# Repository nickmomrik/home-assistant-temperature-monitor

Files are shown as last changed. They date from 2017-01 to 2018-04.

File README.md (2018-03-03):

# Home Assistant - Temperature & Humidity Sensors
My goal with this project was to create a device I could leave in the garage, which would push temperature and humidity data to Home Assistant. I also wanted to be able to enable a "monitor" mode when I turn on the heat in the garage so the system would alert me when a certain temperature was reached. See the [working version on my blog](https://nickmomrik.com/2017/01/13/garage-temperature-sensor-monitor/).

Hardware used:
* [Raspberry Pi Zero](https://www.adafruit.com/products/2885)
* [Miniature WiFi (802.11b/g/n) Module](https://www.adafruit.com/products/814)
* [Adafruit Si7021 Temperature & Humidity Sensor Breakout Board](https://www.adafruit.com/product/3251)
* [RGB backlight negative LCD 20x4](https://www.adafruit.com/products/498)
* [Adafruit Perma-Proto HAT for Pi Mini Kit](https://www.adafruit.com/products/2310)
* [16mm Illuminated Pushbutton](https://www.adafruit.com/products/1477)
* [Panel Mount 10K potentiometer](https://www.adafruit.com/products/562)
* [Potentiometer Knob](https://www.adafruit.com/products/2048)

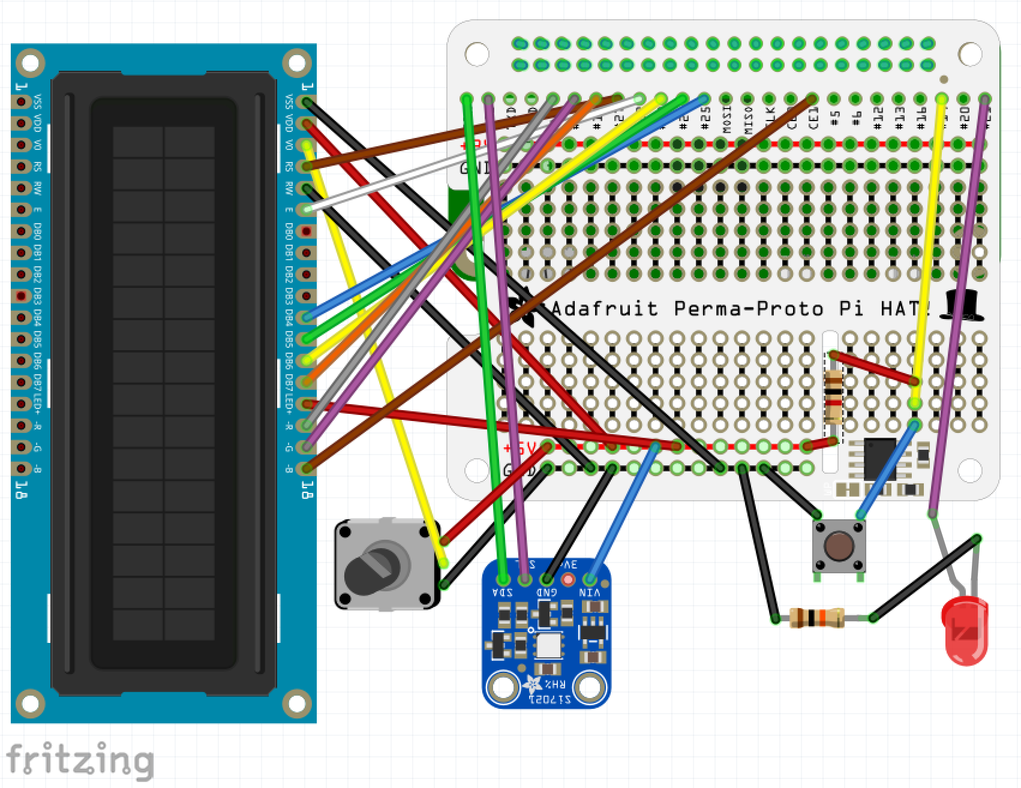
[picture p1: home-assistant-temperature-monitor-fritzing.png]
Home Assistant Temperature Monitor Fritzing


## Installation

* Install [smbus](https://pypi.python.org/pypi/smbus-cffi/0.5.1)
* Install [paho-mqtt](https://pypi.python.org/pypi/paho-mqtt)
* Install [Adafruit_Python_CharLCD](https://github.com/adafruit/Adafruit_Python_CharLCD)
* Install [Adafruit_Python_GPIO](https://github.com/adafruit/Adafruit_Python_GPIO)
* Clone this repo to `/home/pi`
* `cd home-assistant-temperature-monitor`
* `cp config-sample.json config.json`
* Edit `config.json` to set all of the options.
* Get [iOS](https://home-assistant.io/docs/ecosystem/ios/) (or [other notify component](https://home-assistant.io/components/notify/)) and [Dark Sky](https://home-assistant.io/components/sensor.darksky/) working in Home Assistant
* Configure Home Assistant. Here's an example of some `configuration.yaml` settings:

```
homeassistant:
  # You should have a bunch of other
  # settings here in your config
  customize:
    sensor.garage_temperature:
      icon: mdi:thermometer
    sensor.garage_humidity:
      icon: mdi:water-percent
	binary_sensor.garage_heat:
	  icon: mdi:radiator

mqtt_statestream:
  base_topic: ha
  include:
    entities:
      - input_number.garage_target
      - sensor.dark_sky_temperature
      - sensor.dark_sky_humidity

sensor:
  - platform: mqtt
    state_topic: 'garage/temperature'
    name: 'Garage Temperature'
    unit_of_measurement: '°F'

  - platform: mqtt
    state_topic: 'garage/humidity'
    name: 'Garage Humidity'
    unit_of_measurement: '%'

binary_sensor:
  - platform: mqtt
    name: Garage Heat
    state_topic: "garage/heat"
    payload_on: "on"
    payload_off: "off"

input_number:
  garage_target:
    name: Garage Target
    initial: 60
    min: 40
    max: 80
    step: 1
    mode: slider
    icon: mdi:target

group:
  garage:
    name: Garage
    control: hidden
    entities:
        - binary_sensor.garage_heat
        - sensor.garage_temperature
        - input_number.garage_target
        - sensor.garage_humidity

automation:
	- alias: 'Garage temp reached target temp'
	  trigger:
	    platform: state
		entity_id: sensor.garage_temperature
	  condition:
	    condition: and
		conditions:
  		  - condition: state
		    entity_id: binary_sensor.garage_heat
			state: 'on'
  		  - condition: template
		    value_template: '{{ states.sensor.garage_temperature.state >= states.input_number.garage_target.state }}'
	  action:
	    service: notify.ios_IPHONENAME
		data_template:
  		  title: "Garage Target Reached"
  		  message: "Temperature in the garage is {{ states.sensor.garage_temperature.state }}°F"

```
* You probably want to [run this program as a service on your Raspberry Pi](http://www.diegoacuna.me/how-to-run-a-script-as-a-service-in-raspberry-pi-raspbian-jessie/).

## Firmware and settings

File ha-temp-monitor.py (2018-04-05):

#!/usr/bin/python

import math
import time
import os
import sys
import json
import Adafruit_CharLCD as LCD
import paho.mqtt.client as mqtt
import paho.mqtt.publish as publish
import smbus
import RPi.GPIO as GPIO
from datetime import datetime, timedelta

# Setup
with open( "/home/pi/home-assistant-temperature-monitor/config.json" ) as json_file :
    config = json.load( json_file )

GPIO.setmode( GPIO.BCM )
GPIO.setup( config['button_pin'], GPIO.IN )
GPIO.setup( config['led_pin'], GPIO.OUT )
GPIO.output( config['led_pin'], GPIO.LOW )
bus = smbus.SMBus( 1 )
lcd = LCD.Adafruit_RGBCharLCD( config['lcd_rs_pin'], config['lcd_en_pin'],
	config['lcd_d4_pin'], config['lcd_d5_pin'], config['lcd_d6_pin'], config['lcd_d7_pin'],
	config['lcd_columns'], config['lcd_rows'],
	config['lcd_red_pin'], config['lcd_green_pin'], config['lcd_blue_pin'],
	enable_pwm = True )

# Some defaults
prev_rgb     = ( 1, 1, 1 )
status       = 'off'
target_temp  = 0
temp         = 0
out_temp     = 0
humid        = 0
out_humid    = 0
bus_delay    = 0.025
last_update  = 0

# Low Pass Filter
# https://www.norwegiancreations.com/2015/10/tutorial-potentiometers-with-arduino-and-filtering/
filter_alpha = 0.1

# Create degree character
lcd.create_char( 1, [28,20,28,0,0,0,0,0] )

def convert_c_to_f( celcius ) :
	return celcius * 1.8 + 32

# http://stackoverflow.com/a/20792531
def rgb_temp( min_temp, max_temp, temp ) :
	if ( temp < min_temp ) :
		min_temp = temp
	elif ( temp > max_temp ) :
		max_temp = temp

	min_temp = float( min_temp )
	max_temp = float( max_temp )
	ratio = 2 * ( temp - min_temp ) / ( max_temp - min_temp )
	b = int( max( 0, 255 * ( 1 - ratio ) ) )
	r = int( max( 0, 255 * ( ratio - 1 ) ) )
	g = 255 - b - r

	return r, g, b

def get_si7021_data( mode ) :
	# 0x40(64) - SI7021 address
	bus.write_byte( 0x40, mode )
	time.sleep( bus_delay )
	data0 = bus.read_byte( 0x40 )
	data1 = bus.read_byte( 0x40 )
	time.sleep( bus_delay )

	return data0 * 256 + data1

def read_humidity() :
	# 0xF5(245) - Relative Humidity NO HOLD master mode
	return get_si7021_data( 0xF5 ) * 125 / 65536.0 - 6

def read_temperature() :
	# 0xF3(243) - Temperature NO HOLD master mode
	return convert_c_to_f( get_si7021_data( 0xF3 ) * 175.72 / 65536.0 - 46.85 )

def on_connect( client, userdata, flags, rc ) :
	if ( 0 == rc ) :
		client.connected_flag = True
		client.subscribe( [( config['target_temp_topic'], 1 ), ( config['outdoor_temp_topic'], 1 ), ( config['outdoor_humid_topic'], 1)] )

def on_message( client, userdata, msg ) :
	global target_temp, out_temp, out_humid

	value = int( round( float( msg.payload.decode( "utf-8" ) ) ) )
	if ( config['target_temp_topic'] == msg.topic ) :
		target_temp = value
	elif ( config['outdoor_temp_topic'] == msg.topic ) :
		out_temp = value
	elif ( config['outdoor_humid_topic'] == msg.topic ) :
		out_humid = value

def button_is_pressed() :
	return False == GPIO.input( config['button_pin'] )

client = mqtt.Client()
client.connected_flag = False
client.on_connect = on_connect
client.on_message = on_message
client.loop_start()
client.connect( config['ip'] )
while ( not client.connected_flag ) :
	time.sleep( 1 )

try :
	# Initialize before starting filters
	humid = read_humidity()
	temp = read_temperature()
	time.sleep( 2 )

	while ( True ) :
		if ( ( time.time() - last_update ) > config['update_freq'] ) :
			humid = ( filter_alpha * read_humidity() ) + ( ( 1 - filter_alpha ) * humid );
			temp = ( filter_alpha * read_temperature() ) + ( ( 1 - filter_alpha ) * temp );
			client.publish( config['humid_topic'], int( humid ) )
			client.publish( config['temp_topic'], int( temp ) )
			last_update = time.time()

		if ( button_is_pressed() ) :
			if ( 'on' == status ) :
				status = 'off'
				GPIO.output( config['led_pin'], GPIO.LOW )
			else :
				status = 'on'
				GPIO.output( config['led_pin'], GPIO.HIGH )

			# Wait for release
			while ( button_is_pressed() ) :
				time.sleep( 0.1 )

			client.publish( config['status_topic'], status, 2 )

		rgb = rgb_temp( config['low_temp_f'], config['high_temp_f'], temp )
		if ( rgb[0] != prev_rgb[0] or rgb[1] != prev_rgb[1] or rgb[2] != prev_rgb[2] ) :
			lcd.set_color( rgb[0] / 255.0, rgb[1] / 255.0, rgb[2] / 255.0 )
			prev_rgb = rgb

		lcd.set_cursor( 0, 0 )
		lcd.message( datetime.now().strftime( '%H:%M --- %a %b %d' ).upper() + '\nOUTSIDE: {0:3}\x01 {1:2}%\n INSIDE: {2:3}\x01 {3:2}%\n'.format( out_temp, out_humid, int( temp ), int( humid ) ) + ' TARGET: {0:3}\x01'.format( target_temp ).ljust( config['lcd_columns'] ) )

		time.sleep( 0.5 )
except KeyboardInterrupt:
    client.disconnect()
    client.loop_stop()

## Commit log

2017-01-01 Starting to play around with a button for setting the desired temp and changing the LCD color based on cold/hot.
2017-01-01 Use different delays if button is being pressed.
2017-01-03 MQTT Suppor for Home Assistant. Use button to turn on/off Watch "switch".
2017-01-03 Bring back RGB colors based on current temp relative to cold/hot.
2017-01-05 Add variables for pins. Add LED to signal watching status.
2017-01-05 Reset LED to OFF when starting.
2017-01-07 change button pin to 19
2017-01-07 README: use actual sensor name
2017-01-08 Big update!
    * Switch functions and variables to underscore_case.
    * Read Dark Sky temp and humidity from Home Assistant.
    * Clean up some other code.
2017-01-08 Switch looping to be time based instead of counting how many loops were done. Update the LCD less frequently.
2017-01-08 Add uptime. Handle request failures.
    [ha-temp-monitor.py]
2017-01-09 Add Fritzing files
    [home-assistant-temperature-monitor.fzz]
2017-01-09 Had LED connected to the wrong pin
    [home-assistant-temperature-monitor.fzz]
2017-01-09 Fritzing - update resistors
    Didn't realize you could select the values!
    [home-assistant-temperature-monitor.fzz]
2017-01-10 Simplify the Si7021 sensor reading code.
2017-01-14 Remove unused socket.
2017-03-19 Connection errors with HA seem to end up causing a SysCallError exception. Attempt to catch the error and delay retrying updates for 5 minutes.
    [ha-temp-monitor.py]
2017-03-27 Wait until completing all tasks before resetting the last update time.
    [ha-temp-monitor.py]
2018-02-07 Simplify: use a binary sensor that will get triggered when I turn on the button on my device to signify the heater is on. Only push updates to Home Assistant when the temp, humidity, or button state 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
2018-02-15 Have been running into nome back and forth readings, which appear to be due to slight differences when rounding occurs. Implement a simple low pass filter to see if it helps.
2018-03-03 Overhaul! Simplify and replace REST API usage with MQTT
    [ha-temp-monitor.py]
2018-03-06 Switch to uppercase because lowercase letters like g look weird without dropping below.
2018-03-16 Update temp & humidity every 30 seconds and remove the comparison to old values. This should prevent the disconnections and simplifies the logic. Remove an unused variable. Use a single alpha variabl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
    [ha-temp-monitor.py]
2018-03-28 Fix infinite loop caused when pressing the button because parens were missing on the function call. Switch back to timing for updates instead of a loop counter.
    [ha-temp-monitor.py]
